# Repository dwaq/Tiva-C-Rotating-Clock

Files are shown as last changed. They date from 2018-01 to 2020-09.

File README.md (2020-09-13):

# Tiva-C-Rotating-Clock

My sister bought me the [SainSmart Rotating LED Electronic Digital Clock DIY Kit](https://www.sainsmart.com/products/rotating-led-electronic-digital-clock-diy-kit) as a birthday present and after assembling it, it just didn't work. After debugging it for a bit, I realized that Atmel AT89S52 microcontroller wasn't doing anything. I tried to read the memory out, but it was either blank, damaged, or I was locked out. So at this point, I did what any sane engineer would do and spent countless hours designing a PCB adapter board and writing code for another microcontroller so I could use my $10.99 gift.

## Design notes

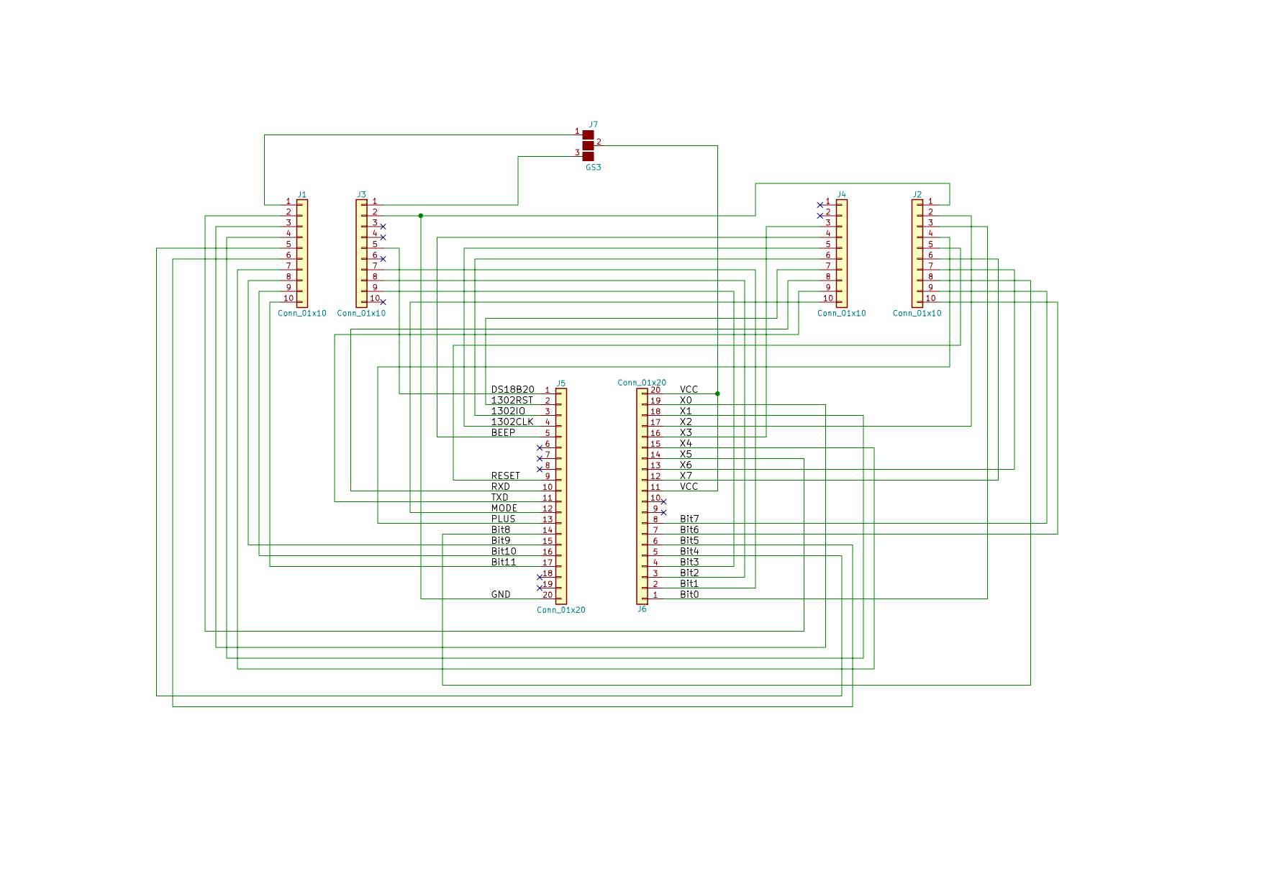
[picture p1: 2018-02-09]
PCB/TivaClock.sch.png

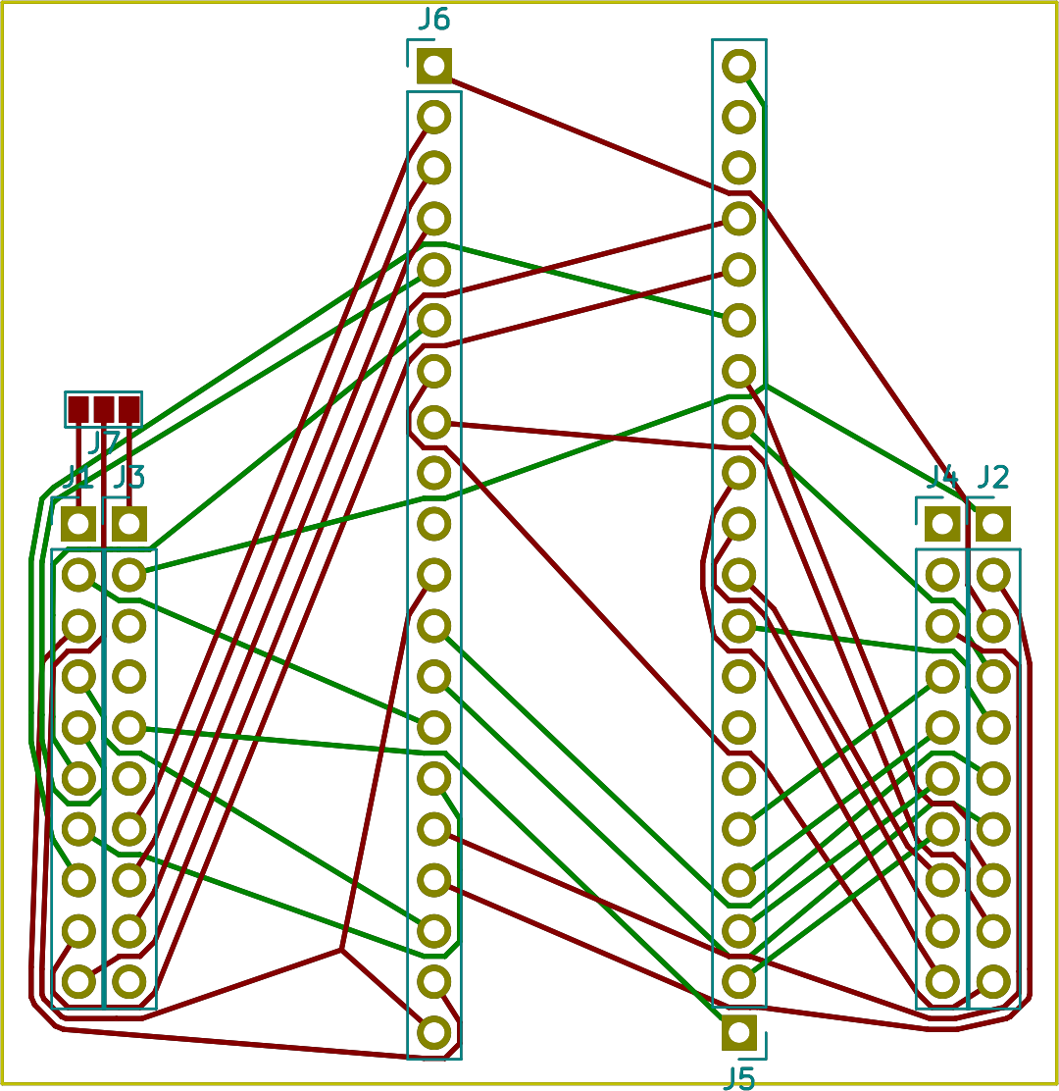
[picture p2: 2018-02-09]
PCB/TivaClock.brd.png

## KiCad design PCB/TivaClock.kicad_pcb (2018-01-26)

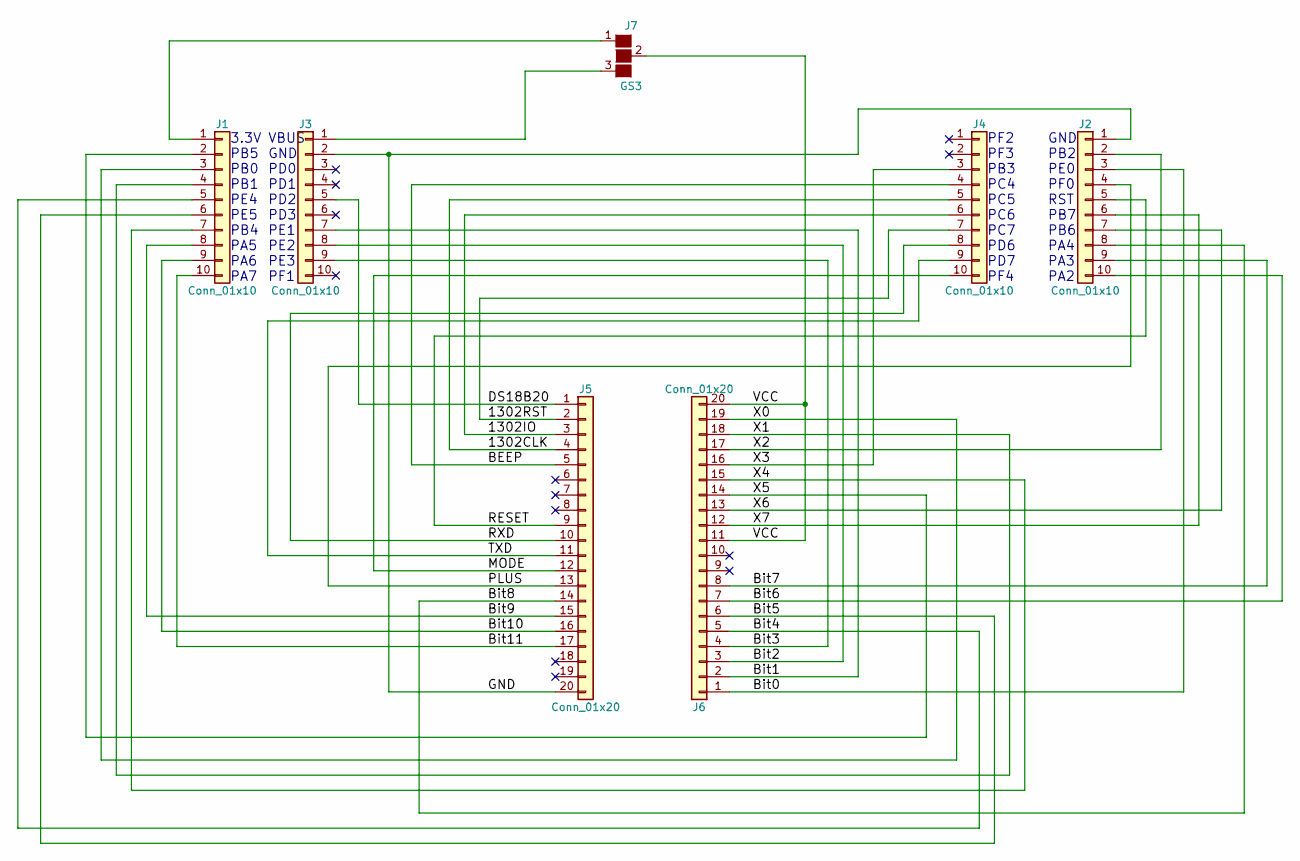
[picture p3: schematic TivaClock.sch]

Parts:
J1, J2, J3, J4: Conn_01x10; Pin_Header_Straight_1x10_Pitch2.54mm
J5, J6: Conn_01x20; Pin_Header_Straight_1x20_Pitch2.54mm
J7: GS3

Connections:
/1302CLK: J4.5, J5.4
/1302IO: J4.6, J5.3
/1302RST: J4.7, J5.2
/BEEP: J4.4, J5.5
/Bit0: J2.3, J6.1
/Bit1: J3.7, J6.2
/Bit2: J3.8, J6.3
/Bit3: J3.9, J6.4
/Bit4: J1.5, J6.5
/Bit5: J1.6, J6.6
/Bit6: J2.10, J6.7
/Bit7: J2.9, J6.8
/Bit8: J2.8, J5.14
/Bit9: J1.8, J5.15
/Bit10: J1.9, J5.16
/Bit11: J1.10, J5.17
/DS18B20: J3.5, J5.1
/GND: J2.1, J3.2, J5.20
/MODE: J4.10, J5.12
/PLUS: J2.4, J5.13
/RESET: J2.5, J5.9
/RXD: J4.8, J5.10
/TXD: J4.9, J5.11
/VCC: J6.11, J6.20, J7.2 (G2)
/X0: J1.3, J6.19
/X1: J1.4, J6.18
/X2: J2.2, J6.17
/X3: J4.3, J6.16
/X4: J1.7, J6.15
/X5: J1.2, J6.14
/X6: J2.7, J6.13
/X7: J2.6, J6.12
unnamed: J1.1, J7.1 (G1)
unnamed: J3.1, J7.3 (G3)

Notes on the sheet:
3.3V PB5 PB0 PB1 PE4 PE5 PB4 PA5 PA6 PA7
VBUS GND PD0 PD1 PD2 PD3 PE1 PE2 PE3 PF1
PF2 PF3 PB3 PC4 PC5 PC6 PC7 PD6 PD7 PF4
GND PB2 PE0 PF0 RST PB7 PB6 PA4 PA3 PA2

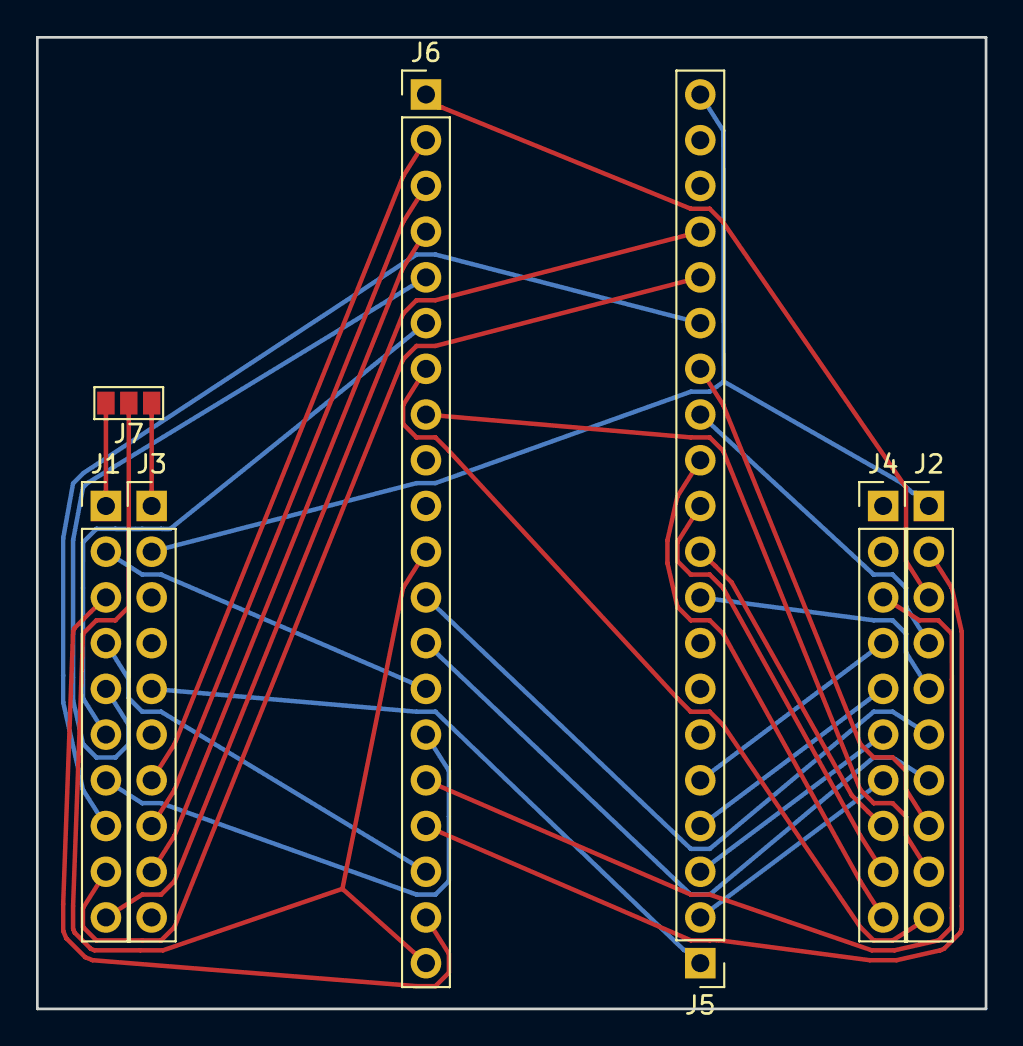
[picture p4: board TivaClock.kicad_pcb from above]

Board: 2 copper layers, 52.7 x 54.0 mm, 7 parts (0 on the bottom side), 34 nets.

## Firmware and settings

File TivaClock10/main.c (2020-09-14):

//*****************************************************************************
//
// main.c
//
//*****************************************************************************

#include <stdint.h>
#include <stdbool.h>
#include "driverlib/debug.h"
#include "driverlib/systick.h"
#include "driverlib/sysctl.h"

#include "rtc.h"
#include "display.h"

//*****************************************************************************
//
// The error routine that is called if the driver library encounters an error.
//
//*****************************************************************************
#ifdef DEBUG
void
__error__(char * pcFilename, uint32_t ui32Line) {
    while (1);
}
#endif

// keep track of time
int hourL,hourR,minL,minR,seconds;

// every second, increase a counter
int refresh = 0;
void everySecond(void) {
    refresh++;
}

int main(void) {

    // set up a interrupt callback function
    SysTickIntRegister((*everySecond));

    // set the SysTick to the same as the system clock, so 1 second
    SysTickPeriodSet(SysCtlClockGet());

     // enable the SysTick
    SysTickEnable();

    // enable the interrupt for the SysTick
    SysTickIntEnable();

    // set up IO for RTC
    rtcSetup();

    // set up IO for display
    displaySetup();

    // Loop forever
    while (1) {
        // when counter has been increased by one second SysTick
        if (refresh != 0) {
            // get time from RTC
            int time = rtcGetTime();

            // format based on datasheet
            hourL = (time & 0b000100000000000000000000) >> 20;
            hourR = (time & 0b000011110000000000000000) >> 16;

            minL = (time & 0b0111000000000000) >> 12;
            minR = (time & 0b0000111100000000) >> 8;

            int secL = (time & 0b01110000) >> 4;
            int secR = (time & 0b00001111);

            seconds = (secL * 10) + secR;

            // reset counter
            refresh = 0;
        }
        // display the time
        displayDigits(hourL, hourR, true, minL, minR);

        // add one to make 0 display at the top-most position
        displaySeconds(seconds+1);
    }
}

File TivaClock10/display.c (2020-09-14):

#include "display.h"
#include "delay.h"

#include <stdint.h>
#include <stdbool.h>
#include "inc/hw_memmap.h"
#include "driverlib/gpio.h"
#include "driverlib/sysctl.h"

#define BLANK 0x10

// set all LED pins to outputs
void displaySetup(void) {
    // Enable the GPIO ports
    SysCtlPeripheralEnable(SYSCTL_PERIPH_GPIOA);
    SysCtlPeripheralEnable(SYSCTL_PERIPH_GPIOB);
    SysCtlPeripheralEnable(SYSCTL_PERIPH_GPIOE);
    SysCtlPeripheralEnable(SYSCTL_PERIPH_GPIOF);

    // Check if the peripheral access is enabled
    while (!SysCtlPeripheralReady(SYSCTL_PERIPH_GPIOA)) {}
    while (!SysCtlPeripheralReady(SYSCTL_PERIPH_GPIOB)) {}
    while (!SysCtlPeripheralReady(SYSCTL_PERIPH_GPIOE)) {}
    while (!SysCtlPeripheralReady(SYSCTL_PERIPH_GPIOF)) {}

    // Set the GPIOs as digital outputs
    GPIOPinTypeGPIOOutput(GPIO_PORTE_BASE, GPIO_PIN_0); // X0
    GPIOPinTypeGPIOOutput(GPIO_PORTE_BASE, GPIO_PIN_1); // X1
    GPIOPinTypeGPIOOutput(GPIO_PORTE_BASE, GPIO_PIN_2); // X2
    GPIOPinTypeGPIOOutput(GPIO_PORTE_BASE, GPIO_PIN_3); // X3
    GPIOPinTypeGPIOOutput(GPIO_PORTE_BASE, GPIO_PIN_4); // X4
    GPIOPinTypeGPIOOutput(GPIO_PORTE_BASE, GPIO_PIN_5); // X5

    GPIOPinTypeGPIOOutput(GPIO_PORTA_BASE, GPIO_PIN_2); // X6
    GPIOPinTypeGPIOOutput(GPIO_PORTA_BASE, GPIO_PIN_3); // X7
    GPIOPinTypeGPIOOutput(GPIO_PORTA_BASE, GPIO_PIN_4); // X8
    GPIOPinTypeGPIOOutput(GPIO_PORTA_BASE, GPIO_PIN_5); // X9
    GPIOPinTypeGPIOOutput(GPIO_PORTA_BASE, GPIO_PIN_6); // X10
    GPIOPinTypeGPIOOutput(GPIO_PORTA_BASE, GPIO_PIN_7); // X11

    GPIOPinTypeGPIOOutput(GPIO_PORTB_BASE, GPIO_PIN_0); // Bit0
    GPIOPinTypeGPIOOutput(GPIO_PORTB_BASE, GPIO_PIN_1); // Bit1
    GPIOPinTypeGPIOOutput(GPIO_PORTB_BASE, GPIO_PIN_2); // Bit2
    GPIOPinTypeGPIOOutput(GPIO_PORTB_BASE, GPIO_PIN_3); // Bit3
    GPIOPinTypeGPIOOutput(GPIO_PORTB_BASE, GPIO_PIN_4); // Bit4
    GPIOPinTypeGPIOOutput(GPIO_PORTB_BASE, GPIO_PIN_5); // Bit5
    GPIOPinTypeGPIOOutput(GPIO_PORTB_BASE, GPIO_PIN_6); // Bit6
    GPIOPinTypeGPIOOutput(GPIO_PORTB_BASE, GPIO_PIN_7); // Bit7
}

// cycle through and display each digit
// dp is for decimal point: 0 for off; 1 for on
void displayDigits(int dig1, int dig2, int dp, int dig3, int dig4) {
    // don't display anything on dig1 if it's '0'
    if(dig1 == 0)
        setDigit(1, BLANK);
    else
        setDigit(1, dig1);

    setDigit(2, dig2);
    setDigit(3, dig3);
    setDigit(4, dig4);
    if (dp) {
        // display decimal point (special parameter)
        decimalpoint();
    }
}

// display a number on the selected digit 1, 2, 3, or 4
void setDigit(int digit, int number) {
    // turn on specific digit
    switch (digit) {
    case 1:
        setSegment(number);
        GPIOPinWrite(GPIO_PORTA_BASE, GPIO_PIN_4, 0); // Bit 8
        Delay(DISPLAY_DELAY);
        GPIOPinWrite(GPIO_PORTA_BASE, GPIO_PIN_4, GPIO_PIN_4); // Bit 8
        break;
    case 2:
        setSegment(number);
        GPIOPinWrite(GPIO_PORTA_BASE, GPIO_PIN_5, 0); // Bit 9
        Delay(DISPLAY_DELAY);
        GPIOPinWrite(GPIO_PORTA_BASE, GPIO_PIN_5, GPIO_PIN_5); // Bit 9
        break;
    case 3:
        setSegment(number);
        GPIOPinWrite(GPIO_PORTA_BASE, GPIO_PIN_6, 0); // Bit 10
        Delay(DISPLAY_DELAY);
        GPIOPinWrite(GPIO_PORTA_BASE, GPIO_PIN_6, GPIO_PIN_6); // Bit 10
        break;
    case 4:
        setSegment(number);
        GPIOPinWrite(GPIO_PORTA_BASE, GPIO_PIN_7, 0); // Bit 11
        Delay(DISPLAY_DELAY);
        GPIOPinWrite(GPIO_PORTA_BASE, GPIO_PIN_7, GPIO_PIN_7); // Bit 11
        break;
        //default:
        // bad - should't be here
    }
}

// display a number or symbol using the 7 segments
// number can be between 0-9 or settings screen uses A-F
void setSegment(int number) {
    // first, reset all segments

    // then set the corresponding segments
    switch (number) {
    case 0:
        // A B C D E F
        GPIOPinWrite(GPIO_PORTB_BASE, 0xFF, 0b11000000);
        break;
    case 1:
        // B C
        GPIOPinWrite(GPIO_PORTB_BASE, 0xFF, 0b11111001);
        break;
    case 2:
        // A B D E G
        GPIOPinWrite(GPIO_PORTB_BASE, 0xFF, 0b10100100);
        break;
    case 3:
        // A B C D G
        GPIOPinWrite(GPIO_PORTB_BASE, 0xFF, 0b10110000);
        break;
    case 4:
        // B C F G
        GPIOPinWrite(GPIO_PORTB_BASE, 0xFF, 0b10011001);
        break;
    case 5:
        // A C D F G
        GPIOPinWrite(GPIO_PORTB_BASE, 0xFF, 0b10010010);
        break;
    case 6:
        // A C D E F G
        GPIOPinWrite(GPIO_PORTB_BASE, 0xFF, 0b10000010);
        break;
    case 7:
        // A B C
        GPIOPinWrite(GPIO_PORTB_BASE, 0xFF, 0b11111000);
        break;
    case 8:
        // A B C D E F G
        GPIOPinWrite(GPIO_PORTB_BASE, 0xFF, 0b10000000);
        break;
    case 9:
        // A B C D F G
        GPIOPinWrite(GPIO_PORTB_BASE, 0xFF, 0b10010000);
        break;
    case 0xA:
        // A B C E F G
        GPIOPinWrite(GPIO_PORTB_BASE, 0xFF, 0b10001000);
        break;
    case 0xB:
        // A B C D E F G
        GPIOPinWrite(GPIO_PORTB_BASE, 0xFF, 0b10000000);
        break;
    case 0xC:
        // A D E F
        GPIOPinWrite(GPIO_PORTB_BASE, 0xFF, 0b11000110);
        break;
    case 0xD:
        // A B C D E F
        GPIOPinWrite(GPIO_PORTB_BASE, 0xFF, 0b11000000);
        break;
    case 0xE:
        // A D E F G
        GPIOPinWrite(GPIO_PORTB_BASE, 0xFF, 0b10000110);
        break;
    case 0xF:
        // A E F G
        GPIOPinWrite(GPIO_PORTB_BASE, 0xFF, 0b10001110);
        break;
    default:
        // case BLANK falls through here
        // turns off all of the segments
        GPIOPinWrite(GPIO_PORTB_BASE, 0xFF, 0b11111111);
        break;
    };
}

void decimalpoint(void) {
    GPIOPinWrite(GPIO_PORTA_BASE, GPIO_PIN_5, 0); // Bit 9
    GPIOPinWrite(GPIO_PORTB_BASE, 0xFF, 0b01111111);
    Delay(TIMER_DELAY);
    GPIOPinWrite(GPIO_PORTA_BASE, GPIO_PIN_5, GPIO_PIN_5); // Bit 9
}
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

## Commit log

2018-01-14 added headers and Clock pin names
    [TivaClock.kicad_pcb, TivaClock.sch]
2018-01-23 add some more stuff
    [TivaClock.sch]
2018-01-24 connect important peripherals
    [TivaClock.sch]
2018-01-24 connected LED wires
    [TivaClock.sch]
2018-01-24 connected all remaining pins
    except power
    [TivaClock.sch]
2018-01-24 annotate clock headers
    [TivaClock.sch]
2018-01-24 place launchpad headers where they belong
    [TivaClock.kicad_pcb]
2018-01-24 added footprints and locations
    [TivaClock.kicad_pcb, TivaClock.sch]
2018-01-26 ignore any temp kicad file
2018-01-26 move clock micro to desired location
    [TivaClock.kicad_pcb]
2018-01-26 orientate it corectly?
    [TivaClock.kicad_pcb]
2018-01-26 export design as specctra file
    [TivaClock.dsn]
2018-01-26 add jumper to connect 3.3V or 5V to board VCC
    [TivaClock.sch]
2018-01-26 put solder jumper on PCB
    [TivaClock.kicad_pcb, TivaClock.sch]
2018-01-26 reroute with solder jumper
    [TivaClock.dsn, TivaClock.kicad_pcb]
2018-01-26 save n exit
    [TivaClock.kicad_pcb]
2018-01-26 add gerber files
    [TivaClock-B.Cu.gbl, TivaClock-B.Mask.gbs, TivaClock-B.SilkS.gbo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]
2018-02-09 Add some no connects to schematic to make ERC happy
    [TivaClock.sch]
2018-02-09 add images of schematic and layout
2018-02-10 Add pin names to launchpad headers
    [TivaClock.sch]
2018-02-11 add code that drives all LEDs
2018-02-11 Add all driverlib files for chip
2020-08-29 Set up SysTick for 1 second interrupt
2020-08-29 Change RTC I/O pin & get comms working
2020-08-29 combine seconds and display on LED ring
2020-09-13 Convert bit-banged pins to I2C3 (PD0/PD1)
2020-09-14 Move KiCad files into PCB directory
    [TivaClock-B.Cu.gbl, TivaClock-B.Mask.gbs, TivaClock-B.SilkS.gbo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]
2020-09-14 Switch order of LED pin writes to illuminate them better
2020-09-14 Switch order of Display pin writes to illuminate them better
